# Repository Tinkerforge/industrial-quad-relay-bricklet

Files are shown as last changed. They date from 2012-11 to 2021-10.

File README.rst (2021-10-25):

Industrial Quad Relay Bricklet
==============================

This repository contains the firmware source code and the hardware design
files. The documentation generator configs can be found at
https://github.com/Tinkerforge/generators

Repository Content
------------------

software/:
 * examples/: Examples for all supported languages
 * build/: Compiled files
 * src/: Source code of firmware
 * Makefile: Makefile to build project

hardware/:
 * Contains KiCad project files and additionally schematics as PDF

datasheets/:
 * Contains datasheets for sensors and complex ICs that are used

Hardware
--------

The hardware is designed with the open source EDA Suite KiCad
(http://www.kicad.org). Before you are able to open the files,
you have to install the Tinkerforge kicad-libraries
(https://github.com/Tinkerforge/kicad-libraries). You can either clone
them directly in hardware/ or clone them in a separate folder and
symlink them into hardware/
(ln -s kicad_path/kicad-libraries project_path/hardware). After that you
can open the .pro file in hardware/ with KiCad and from there view and
modify the schematics and the PCB layout.

Software
--------

If you want to do your own Brick/Bricklet firmware development we highly
recommend that you use our build environment setup script and read the
tutorial (https://www.tinkerforge.com/en/doc/Tutorials/Tutorial_Build_Environment/Tutorial.html).

To compile the C code we recommend you to install the newest GNU Arm Embedded
Toolchain (https://launchpad.net/gcc-arm-embedded/+download).
You also need to install bricklib (https://github.com/Tinkerforge/bricklib)
and brickletlib (https://github.com/Tinkerforge/brickletlib).

You can either clone it directly in software/src/ or clone it in a
separate folder and symlink it into software/src/
(ln -s bricklib_path/bricklib project_path/software/src/ and
ln -s brickletlib_path/brickletlib project_path/software/src/).
Finally make sure to have CMake installed
(http://www.cmake.org/cmake/resources/software.html).

After that you can build the firmware by invoking make in software/.
The firmware (.bin) can then be found in software/build/ and uploaded
with brickv (click button "Flashing" on start screen).

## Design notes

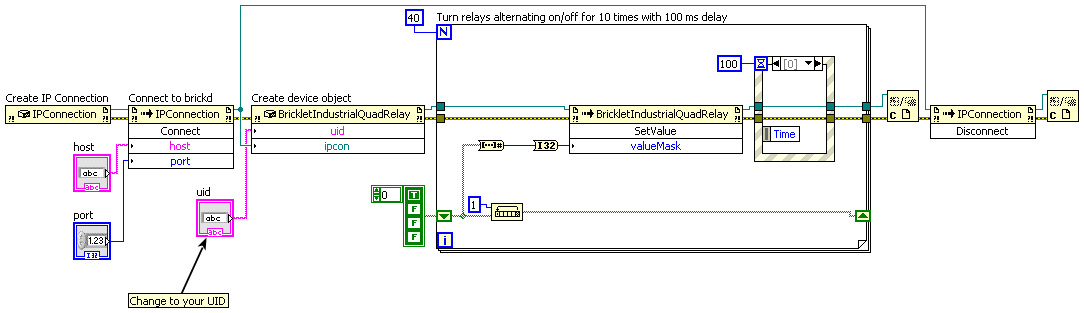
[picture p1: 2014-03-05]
software/examples/labview/Example Simple.vi.png

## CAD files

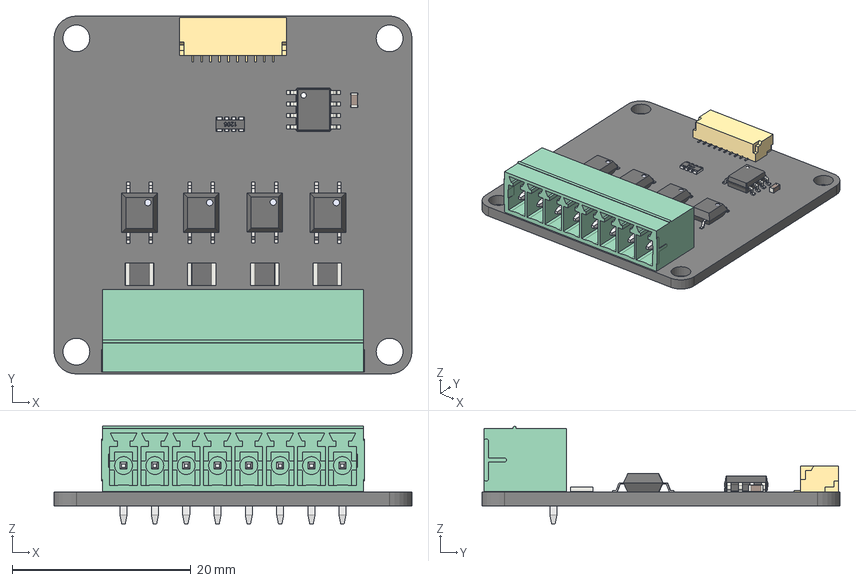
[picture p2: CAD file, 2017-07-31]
hardware/industrial-quad-relay.step
40.0 x 40.0 x 10.9 mm

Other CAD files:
hardware/industrial-quad-relay.FCStd

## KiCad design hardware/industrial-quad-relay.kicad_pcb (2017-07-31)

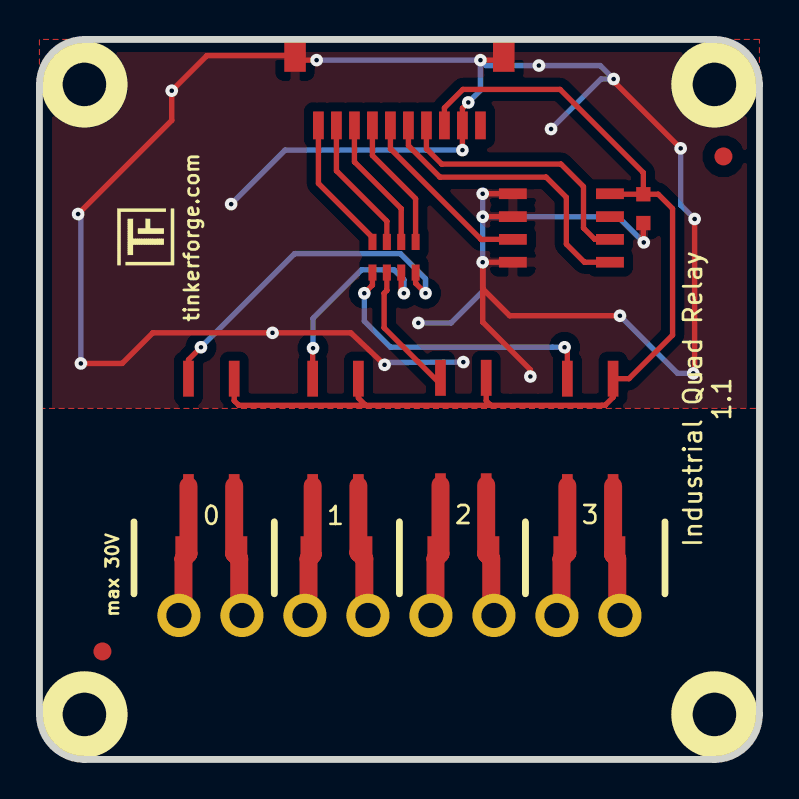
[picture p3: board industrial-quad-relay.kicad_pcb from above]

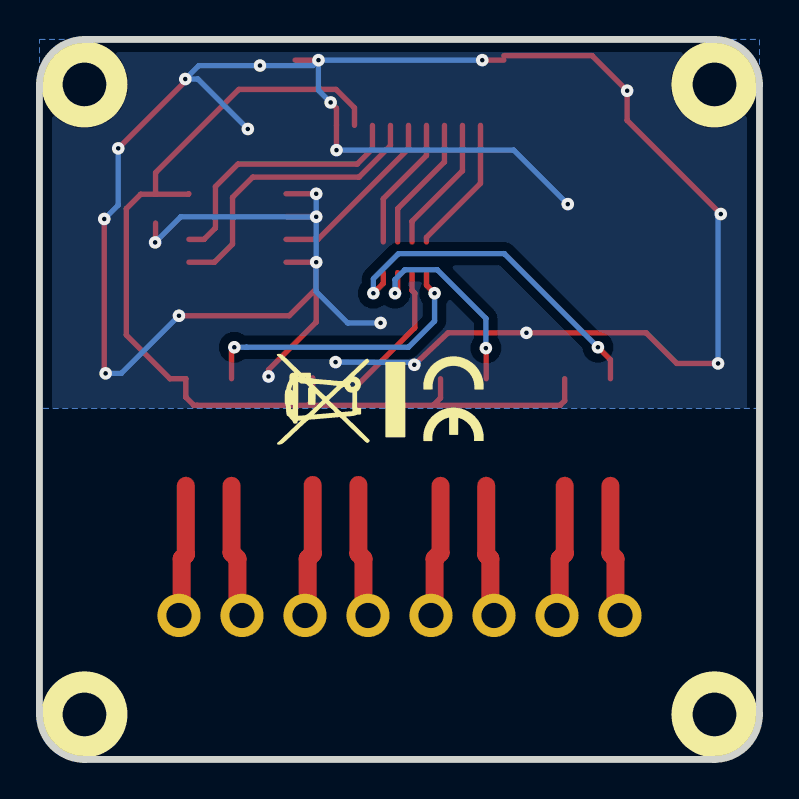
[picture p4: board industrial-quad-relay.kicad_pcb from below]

Board: 2 copper layers, 40.0 x 40.0 mm, 21 parts (2 on the bottom side), 21 nets.

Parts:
C1: 100nF; C0603
Fiducial_Mark: VAL**; Fiducial_Mark
Fiducial_Mark#2: VAL**; Fiducial_Mark
P1: CON-SENSOR
P2: Digital Output; OQ_8P
R1, R2, R3, R4: VJ13PC0300KBA; R1210
RP1: 1k; 0603X4
U1: M24C64; SOIC8
U2, U3, U4, U5: CPC1020N; SOP4-WIDE
U6, U7, U8, U9: DRILL; DRILL_NP
VAL: CE_5mm
VAL#2: WEEE_7mm

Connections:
3V3: C1.1, P1.3, U1.8, U2.1, U3.1, U4.1, U5.1
GND: C1.2, P1.2, P1.EP, U1.1, U1.2, U1.4
unnamed: P1.4, U1.6
unnamed: P1.5, U1.5
unnamed: P1.6, U1.3
unnamed: P2.1, R1.1, U2.3
unnamed: P2.2, R1.2, U2.4
unnamed: P2.3, R2.1, U3.3
unnamed: P2.4, R2.2, U3.4
unnamed: P2.5, R3.1, U4.3
unnamed: P2.6, R3.2, U4.4
unnamed: P2.7, R4.1, U5.3
unnamed: P2.8, R4.2, U5.4
unnamed: RP1.5, U5.2
unnamed: RP1.6, U4.2
unnamed: RP1.7, U3.2
unnamed: RP1.8, U2.2
OUTPUT1: P1.7, RP1.1
OUTPUT2: P1.8, RP1.2
OUTPUT3: P1.9, RP1.3
OUTPUT4: P1.10, RP1.4

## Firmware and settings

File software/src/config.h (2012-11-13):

/* industrial-quad-relay-bricklet
 * Copyright (C) 2012 Olaf Lüke <olaf@tinkerforge.com>
 *
 * config.h: Industrial Quad Relay Bricklet specific configuration
 *
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
 * You should have received a copy of the GNU Lesser General Public
 * License along with this library; if not, write to the
 * Free Software Foundation, Inc., 59 Temple Place - Suite 330,
 * Boston, MA 02111-1307, USA.
 */

#ifndef CONFIG_H
#define CONFIG_H

#include <stdint.h>
#include <stdbool.h>

#include "bricklib/drivers/board/sam3s/SAM3S.h"
#include "bricklib/drivers/pio/pio.h"
#include "brickletlib/bricklet_entry.h"

#include "quad_relay.h"

#define BRICKLET_FIRMWARE_VERSION_MAJOR 2
#define BRICKLET_FIRMWARE_VERSION_MINOR 0
#define BRICKLET_FIRMWARE_VERSION_REVISION 0

#define BRICKLET_HARDWARE_VERSION_MAJOR 1
#define BRICKLET_HARDWARE_VERSION_MINOR 0
#define BRICKLET_HARDWARE_VERSION_REVISION 0

#define BRICKLET_DEVICE_IDENTIFIER 225

#define INVOCATION_IN_BRICKLET_CODE
#define PIN0 (BS->pin1_ad)
#define PIN1 (BS->pin2_da)
#define PIN2 (BS->pin3_pwm)
#define PIN3 (BS->pin4_io)

#define NUM_PINS 16

#define MAGIC_NUMBER_INDUSTRIAL_QUAD_RELAY_1 1093122344L
#define MAGIC_NUMBER_INDUSTRIAL_QUAD_RELAY_2 2096912907L

typedef struct {
	Pin *pins[NUM_PINS];
	uint32_t time[NUM_PINS];
	uint32_t time_remaining[NUM_PINS];
	uint16_t monoflop_callback_mask;
	char group[4];
	uint32_t counter;
	uint32_t magic_number1;
	uint32_t magic_number2;
} BrickContext;

#endif

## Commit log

2012-09-21 Initial Quad Relay commit
2012-11-28 Industrial Quad Relay hardware files added
    [industrial-quad-relay.brd, industrial-quad-relay.sch]
2014-04-02 perl: Unify print style
2015-03-26 update hardware files
    [industrial-quad-relay.brd, industrial-quad-relay.kicad_pcb, industrial-quad-relay.sch]
2015-08-07 Use full device class name in Python example
2016-05-18 c: Add missing device destroy call
2017-07-31 Add 3d information (final)
    [industrial-quad-relay.kicad_pcb, industrial-quad-relay.sch]
2017-07-31 Add 3d model (*.step & *.FCStd)
    [industrial-quad-relay.FCStd, industrial-quad-relay.step]
2018-02-20 Cleanup KiCad libraries config
    Ensure LibDir=kicad-libraries and LibName1=tinkerforge.
    Remove special library.
2021-10-25 Update KiCad link
    https://www.kicad.org/blog/2021/10/Avoid-links-to-former-kicad-domain/

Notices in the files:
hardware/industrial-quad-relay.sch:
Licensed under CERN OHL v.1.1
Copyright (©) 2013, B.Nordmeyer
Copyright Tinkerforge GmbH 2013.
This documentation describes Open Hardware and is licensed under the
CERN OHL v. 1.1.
